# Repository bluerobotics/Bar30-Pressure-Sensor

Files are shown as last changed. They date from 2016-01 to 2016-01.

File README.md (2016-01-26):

# Bar30 Pressure Sensor

Arduino software library is available [here](http://github.com/bluerobotics/BlueRobotics_MS5837_Library/).

The schematic and board layout are designed in EagleCAD.

# Hardware

## Description

The Bar30 pressure sensor is a high-pressure, high-resolution pressure sensor that is sealed from the water and ready to install in a watertight enclosure. With 0.2 bar resolution, it has an amazing depth measurement resolution of 2mm in the water column!

The sensor is the Measurement Specialties MS5837-30BA, which can measure up to 30 bar (300m depth) and communicates over I2C. It comes standard with a 4-pin DF13 connector and compatible with most DroneCode compatible boards including the APM2.6, PixHawk, and others.

## Features

* Measure up to 300m water depth with 2mm resolution
* Reverse polarity protection
* Standard DF13 connector for connection to DroneCode boards such as APM, PixHawk, Navio2, etc.
* Sealed in a bulkhead penetrator for easy installation into any 10mm hole

## Compatibility

The Bar30 sensor is compatible with any device with 3.3V I<sup>2</sup>C logic. When using with a 5V device, such as an Arduino Uno, it is necessary to use a logic level converter.

##Configuration

--

##Ratings

**Electrical:**

| **Item** | **Condition** | **Value** |
| ---: | :---: | --- |
| Supply Voltage| - | 2.5-5.5 volts |
| I<sup>2</sup>C Logic Voltage | - | 2.5-3.6 volts |
| Peak Current | - | 1.25 mA |

**Pressure:**

| **Item** | **Condition** | **Value** |
| ---: | :---: | --- |
| Maximum Mechanical Pressure | - | 50 bar |
|Operating Pressure| - |0-30 bar [up to 1000 ft (300 m) in water]|
|Absolute Accuracy  (0-40&deg;C) | From 0-6 bar | +/- 50 mbar 	(51 cm in freshwater)		 |
|  				 | From 0-20 bar | +/- 100 mbar (102 cm in freshwater)			 |
|				 | From 0-30 bar | +/- 200 mbar (204 cm in freshwater) 	 |
|Absolute Accuracy (-25-85&deg;C)| From 0-6 bar | +/- 100 mbar 	(102 cm in freshwater)		 |
|  				 | From 0-20 bar | +/- 200 mbar (204 cm in freshwater)			 |
|				 | From 0-30 bar | +/- 400 mbar (408 cm in freshwater) 	 |

**Temperature:**

| **Item** | **Condition** | **Value** |
| ---: | :---: | --- |
| Operating Temperature | - | -20 to +85&deg;C |
| Storage Temperature | - | -40 to +85&deg;C |
| Absolute Accuracy | From 0-10 bar at 0-60&deg;C | +/- 1.5&deg;C |
| | From 0-30 bar at -20-85&deg;C |  +/- 4.0&deg;C |

**Physical:**

| **Item** | **Value** |
| ---: | --- |
| Wire Colors | Green - I<sup>2</sup>C Clock (SCL) |
| | White - I<sup>2</sup>C Data (SDA)  |
| | Red - Positive (2.5-5.5V) |
| | Black - Ground |
| Overall Length | 37 mm |
| Thread Size | M10x1.5 20 mm threaded |
| Recommended Through Hole Size | 10-11 mm |
| Wrench Flats | 16 mm |

##Example Setups

Examples TBD

##Physical Specifications

* Bulkhead hole size: 10-10.5mm
* Wire length: 11" (280mm)

##License

The Bar30 Pressure Sensor Hardware Design is released under the MIT License.

##Revision History

0.0 - Under development

0.1 - First production version (marked with rev4)

0.2 - Minor layout changes (marked with rev5)

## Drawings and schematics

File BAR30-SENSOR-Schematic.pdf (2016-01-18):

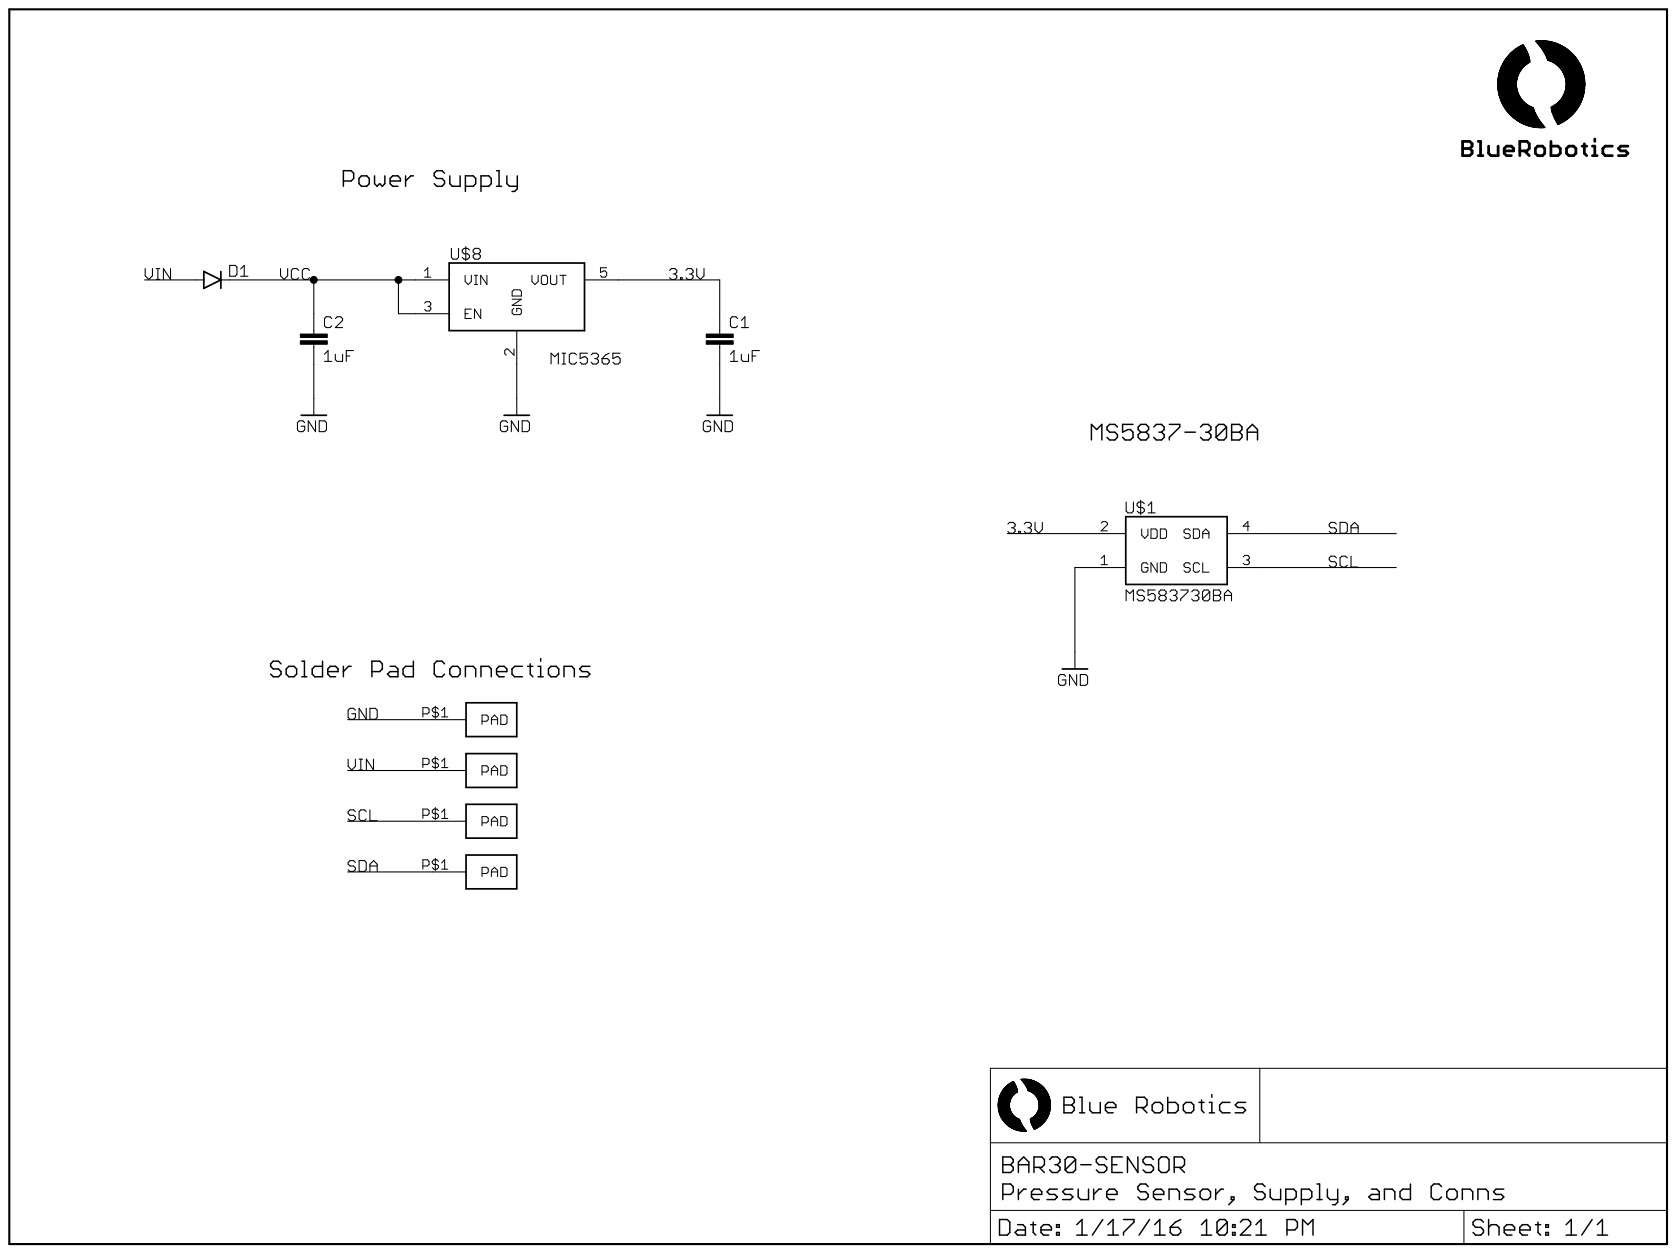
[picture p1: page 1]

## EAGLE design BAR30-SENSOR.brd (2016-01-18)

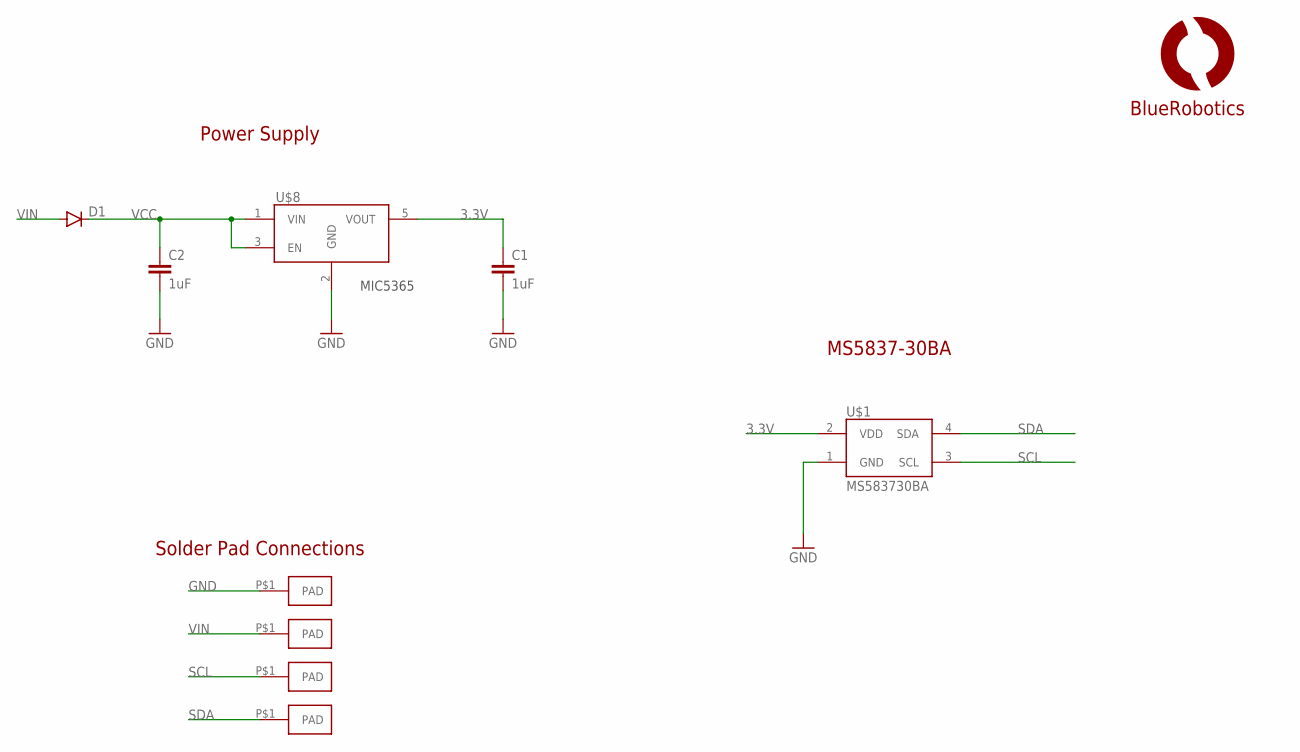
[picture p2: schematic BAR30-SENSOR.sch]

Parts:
C1, C2: 1uF; C0402
D1: DIODESOD523; SOD523
U$1: MS583730BA; MS5837
U$3, U$4, U$5, U$6: PAD1.5X3MM; PAD-1.5X3MM
U$7: LOGOBR-LOGO-S; BR-LOGO-SMALL
U$8: VREG-MIC5365; SC70-5L

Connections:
3.3V: C1.1, U$1.2 (VDD), U$8.5 (VOUT)
GND: C1.2, C2.2, U$1.1 (GND), U$3.P$1, U$8.2 (GND)
SCL: U$1.3 (SCL), U$5.P$1
SDA: U$1.4 (SDA), U$6.P$1
VCC: C2.1, D1.C, U$8.1 (VIN), U$8.3 (EN)
VIN: D1.A, U$4.P$1

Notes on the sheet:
Solder Pad Connections
MS5837-30BA
Power Supply
MIC5365

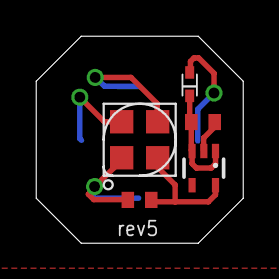
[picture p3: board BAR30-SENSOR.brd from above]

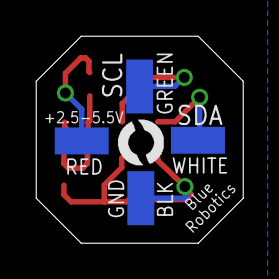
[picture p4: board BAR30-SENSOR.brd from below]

Board: 2 copper layers, 11.5 x 11.5 mm, 10 parts (5 on the bottom side), 6 nets.

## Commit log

2015-10-21 Initial commit with board files, DXF script, and README
    [BAR30-SENSOR.brd, BAR30-SENSOR.sch]
2015-11-02 Updated frame.
    [BAR30-SENSOR.brd, BAR30-SENSOR.sch]
2015-11-03 Change voltage regulator from zener to LDO.
    [BAR30-SENSOR.brd, BAR30-SENSOR.sch]
2015-11-16 Fixed incorrect regulator footprint.
    [BAR30-SENSOR.brd, BAR30-SENSOR.sch]
2015-12-22 Added a ground via and change silk screen on bottom to reflect proper voltage range.
    [BAR30-SENSOR.brd]
2015-12-22 A few minor aesthetic changes. Ordering this version.
    [BAR30-SENSOR.brd]
2016-01-10 Added PDF schematic, updated readme.
    [BAR30-SENSOR.sch]
2016-01-18 Last minute major redesign for DroneCode I2C compatibility.
    PixHawk and others cannot handle 5V I2C logic but have 5V I2C power supplies!
    [BAR30-SENSOR.brd, BAR30-SENSOR.sch]

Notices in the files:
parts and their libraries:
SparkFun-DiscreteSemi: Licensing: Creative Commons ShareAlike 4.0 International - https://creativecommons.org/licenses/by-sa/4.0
